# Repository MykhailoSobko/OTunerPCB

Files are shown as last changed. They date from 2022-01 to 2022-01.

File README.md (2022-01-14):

# OTunerPCB
Schematics and PCB for the OTuner - optical guitar tuner, which uses stroboscopic effect instead of sound.

The project was done as a part of Principles of Computer Organization course at UCU in association with mentors from Renesas company.

The ```main``` branch contains files that ended up as a final version for the student project and the ```dev``` branch contains files for future development as a standalone project.

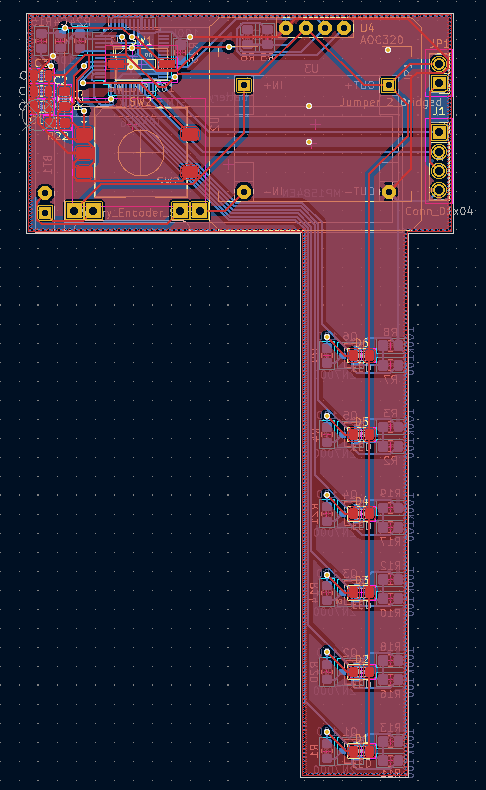
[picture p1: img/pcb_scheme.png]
  
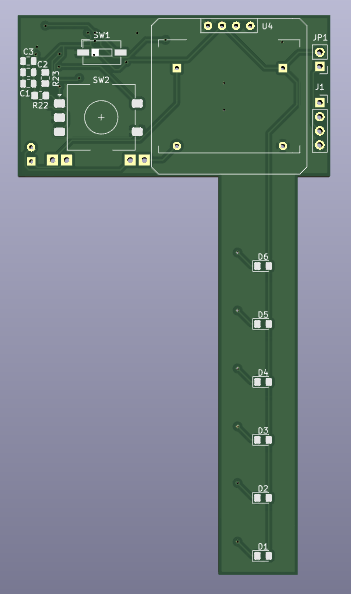
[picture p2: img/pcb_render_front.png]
  
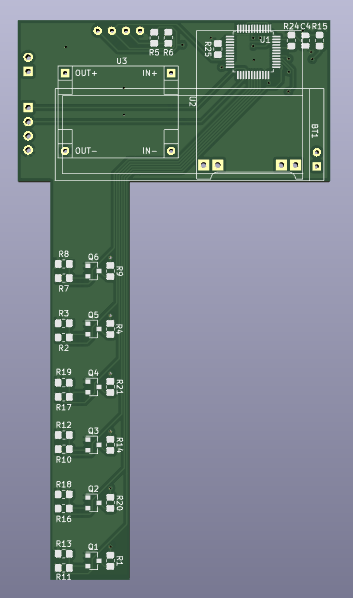
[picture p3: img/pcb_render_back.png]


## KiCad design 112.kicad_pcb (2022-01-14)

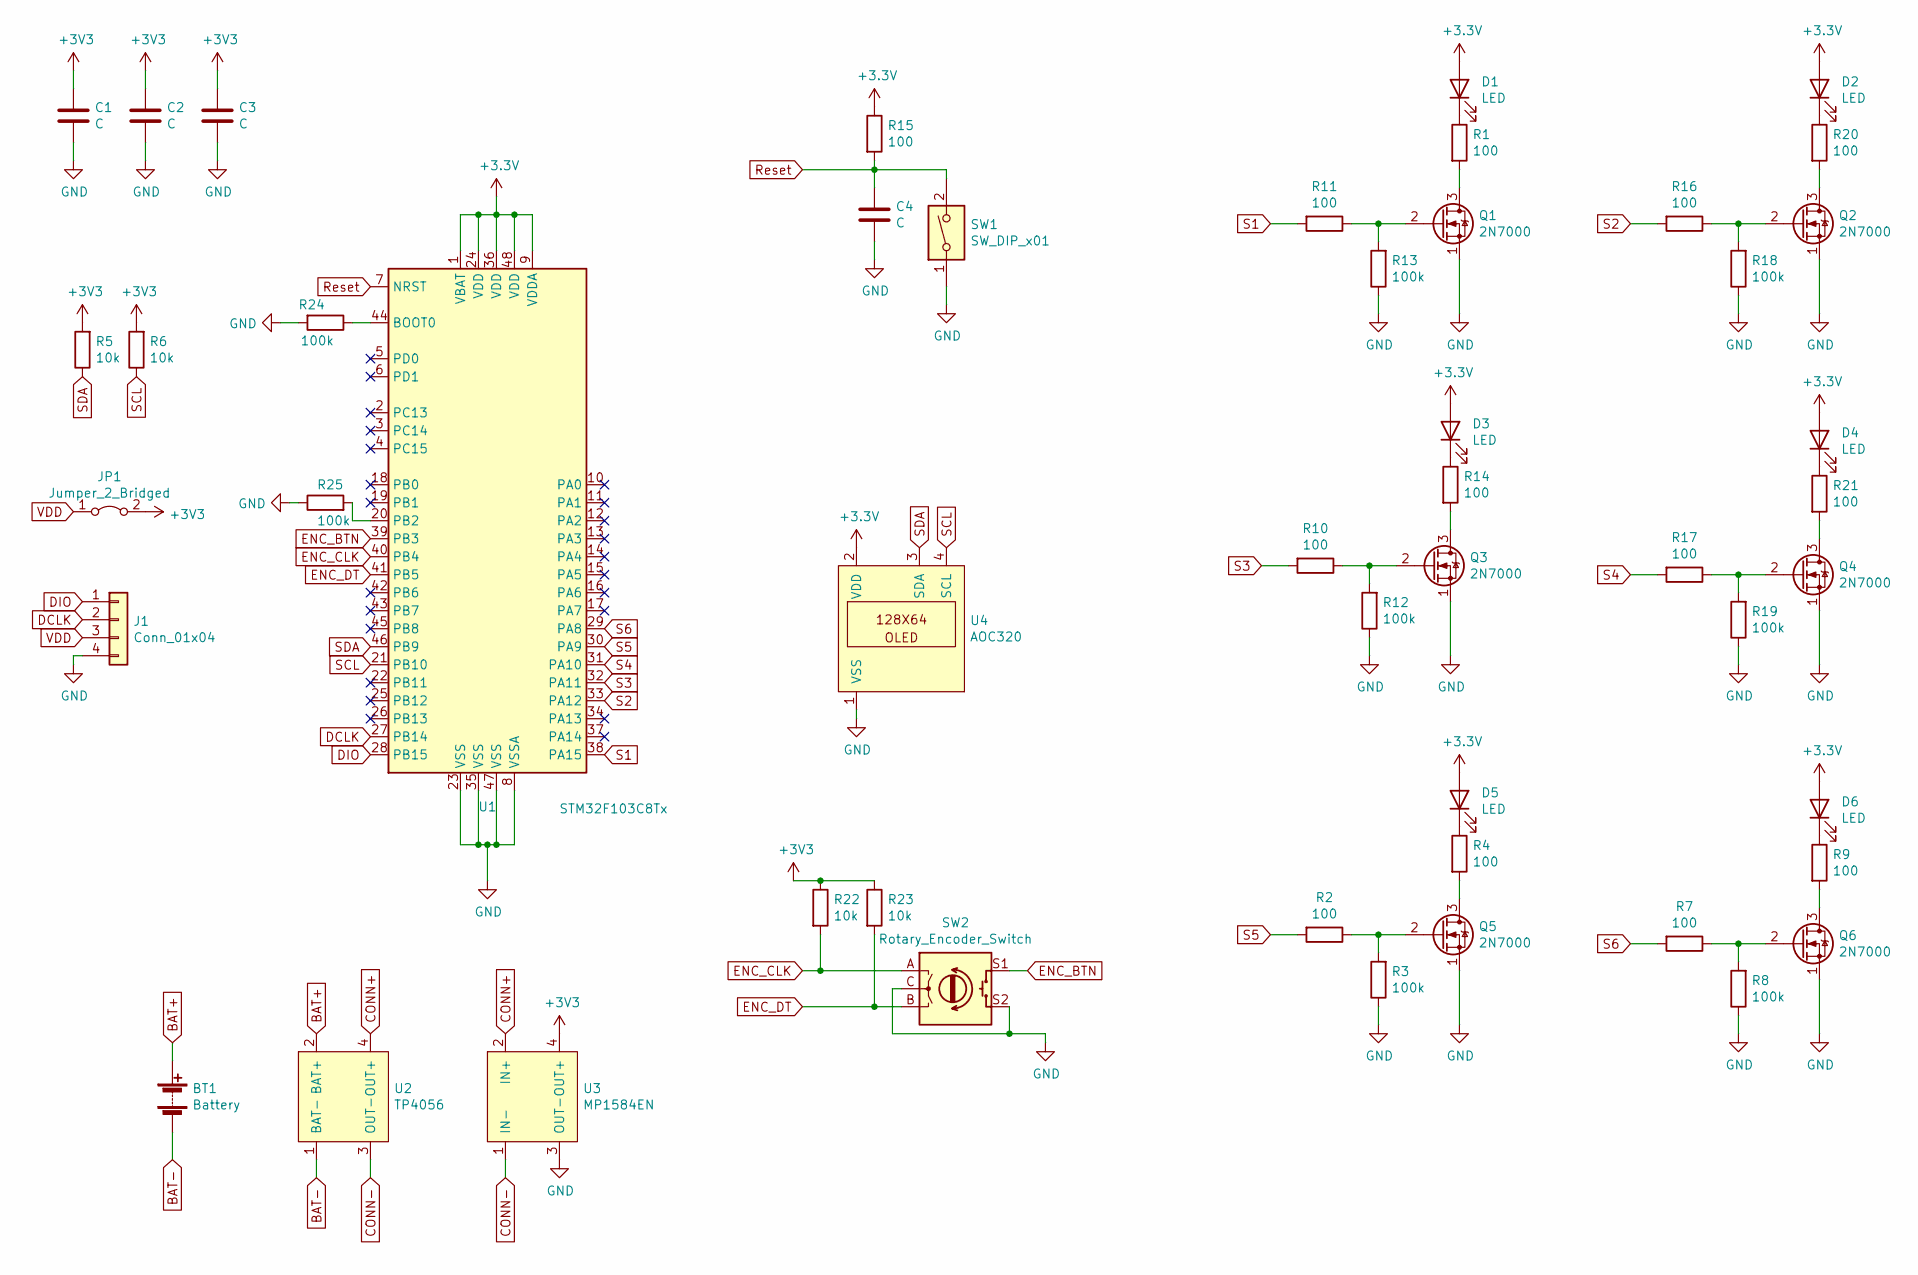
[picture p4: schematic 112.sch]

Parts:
BT1: Battery; RAC163
C1, C2, C3, C4: C; C_0805_2012Metric
D1, D2, D3, D4, D5, D6: LED; LED_0805_2012Metric_Pad1.15x1.40mm_HandSolder
J1: Conn_01x04; PinSocket_1x04_P2.54mm_Vertical
JP1: Jumper_2_Bridged; PinHeader_1x02_P2.54mm_Vertical
Q1, Q2, Q3, Q4, Q5, Q6: 2N7000; SOT-23
R1, R2, R4, R7, R9, R10, R11, R14, R15, R16, R17, R20, R21: 100; R_0805_2012Metric_Pad1.20x1.40mm_HandSolder
R3, R8, R12, R13, R18, R19, R24, R25: 100k; R_0805_2012Metric_Pad1.20x1.40mm_HandSolder
R5, R6, R22, R23: 10k; R_0805_2012Metric_Pad1.20x1.40mm_HandSolder
SW1: SW_DIP_x01; SW_DIP_SPSTx01_Slide_6.7x4.1mm_W6.73mm_P2.54mm_LowProfile_J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
SW2: Rotary_Encoder_Switch; EC1102S-4A-F1
U1: STM32F103C8Tx; LQFP-48_7x7mm_P0.5mm
U2: TP4056
U3: MP1584EN
U4: AOC320

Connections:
BAT+: BT1.1 (+), U2.2 (BAT+)
BAT-: BT1.2 (-), U2.1 (BAT-)
CONN+: U2.4 (OUT+), U3.2 (IN+)
CONN-: U2.3 (OUT-), U3.1 (IN-)
DCLK: J1.2, U1.27 (PB14)
DIO: J1.1, U1.28 (PB15)
ENC_BTN: SW2.S1, U1.39 (PB3)
ENC_CLK: R22.2, SW2.A, U1.40 (PB4)
ENC_DT: R23.2, SW2.B, U1.41 (PB5)
GND: C1.2, C2.2, C3.2, C4.2, J1.4, Q1.1 (S), Q2.1 (S), Q3.1 (S), Q4.1 (S), Q5.1 (S), Q6.1 (S), R3.1, R8.1, R12.1, R13.1, R18.1, R19.1, R24.2, R25.1, SW1.1, SW2.C, SW2.S2, U1.8 (VSSA), U1.23 (VSS), U1.35 (VSS), U1.47 (VSS), U3.3 (OUT-), U4.1 (VSS)
unnamed: D1.1 (K), R1.1
unnamed: D2.1 (K), R20.1
unnamed: D3.1 (K), R14.1
unnamed: D4.1 (K), R21.1
unnamed: D5.1 (K), R4.1
unnamed: D6.1 (K), R9.1
unnamed: Q1.2 (G), R11.1, R13.2
unnamed: Q1.3 (D), R1.2
unnamed: Q2.2 (G), R16.1, R18.2
unnamed: Q2.3 (D), R20.2
unnamed: Q3.2 (G), R10.1, R12.2
unnamed: Q3.3 (D), R14.2
unnamed: Q4.2 (G), R17.1, R19.2
unnamed: Q4.3 (D), R21.2
unnamed: Q5.2 (G), R2.1, R3.2
unnamed: Q5.3 (D), R4.2
unnamed: Q6.2 (G), R7.1, R8.2
unnamed: Q6.3 (D), R9.2
unnamed: R24.1, U1.44 (BOOT0)
unnamed: R25.2, U1.20 (PB2)
Reset: C4.1, R15.2, SW1.2, U1.7 (NRST)
S1: R11.2, U1.38 (PA15)
S2: R16.2, U1.33 (PA12)
S3: R10.2, U1.32 (PA11)
S4: R17.2, U1.31 (PA10)
S5: R2.2, U1.30 (PA9)
S6: R7.2, U1.29 (PA8)
SCL: R6.1, U1.21 (PB10), U4.4 (SCL)
SDA: R5.1, U1.46 (PB9), U4.3 (SDA)
VDD: J1.3, JP1.1 (A)

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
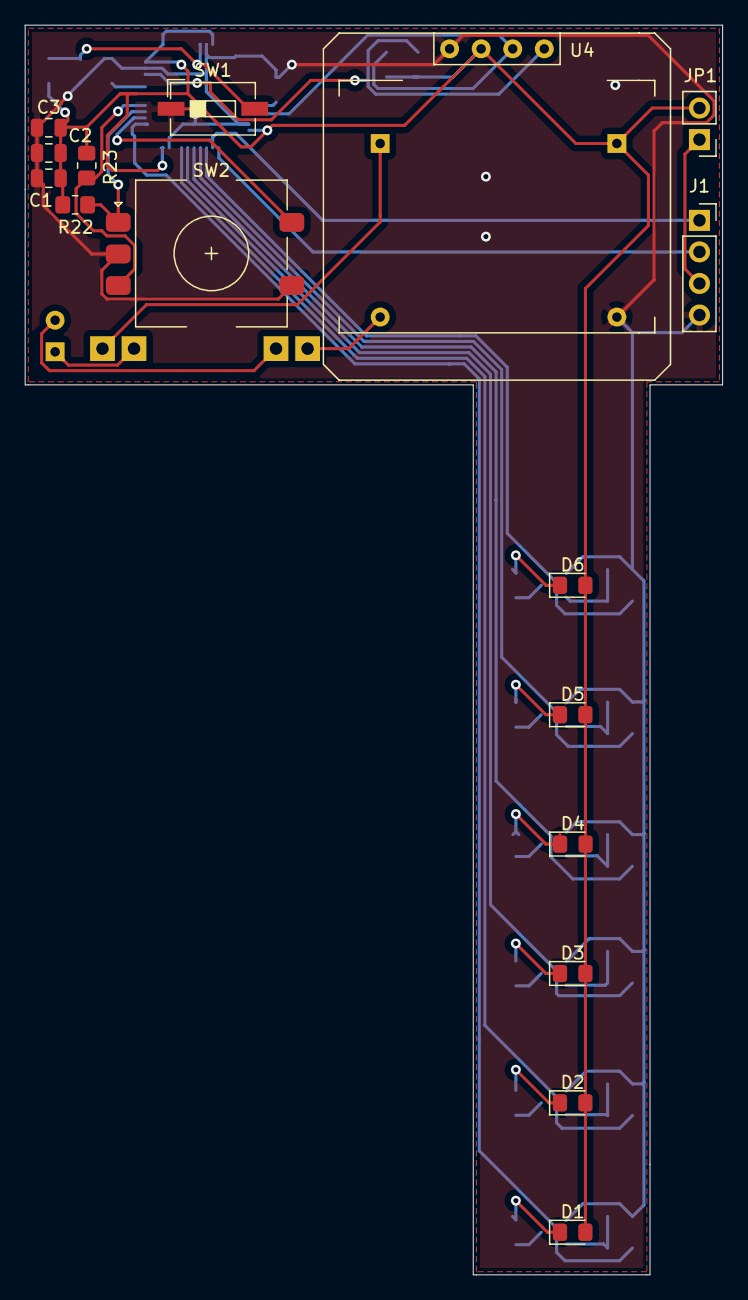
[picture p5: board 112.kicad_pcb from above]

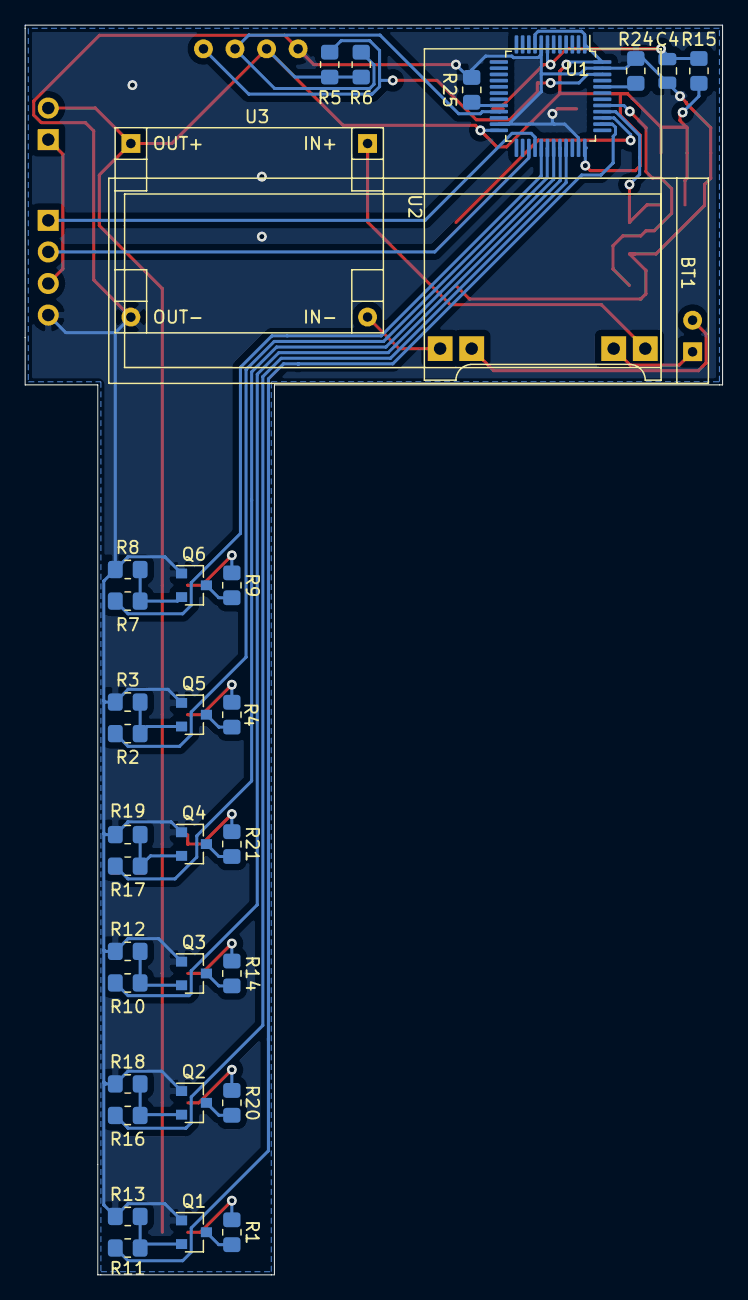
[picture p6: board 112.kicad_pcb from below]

Board: 2 copper layers, 56.1 x 100.6 mm, 50 parts (34 on the bottom side), 41 nets.
